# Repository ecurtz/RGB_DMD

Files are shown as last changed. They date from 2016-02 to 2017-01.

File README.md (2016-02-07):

# RGB_DMD LED Matrix Display for Pinball #

RGB_DMD is software for displaying either colorized signals from a pinball machine or color images from a host PC onto RGB LED matrix displays using the [Teensy 3.2](http://www.pjrc.com/teensy/index.html) development board and a custom carrier board. RGB_DMD was written by Eli Curtz, <eli@nuprometheus.com> but is built on top of open source work by many people, primarily the [SmartMatrix](http://docs.pixelmatix.com/SmartMatrix/library.html) display library.

## Contents ##
### License ###
The RGB_DMD source code is released under the MIT License.
### HEX Folder ###
Contains compiled .hex versions of the project, which can be loaded directly to the board using the Teensy Loader  or Teensy Qt applications.
### SRC Folder ###
Contains the Arduino / C++ source code for the project.
### UTIL Folder ###
Utilities for testing and configuring data.

## Building RGB_DMD ##

### Tools ###
[Arduino IDE](http://arduino.cc/en/main/software) is required for recompiling RGB_DMD from source or customizing the code.

[Teensyduino](http://www.pjrc.com/teensy/td_download.html) is a required plugin that adds Teensy support to the Arduino IDE as well as the Teensy Loader tool for transferring compiled code to the development board.

### Libraries
These are additional third party code required when building RGB_DMD. They are distributed as source on github and are installed as described under __Manual Installation__ at the [Arduino reference](https://www.arduino.cc/en/Guide/Libraries#toc5).

[SmartMatrix](https://github.com/ecurtz/SmartMatrix) is used for outputting the signal to the RGB matrix. Link is to my fork which is required for hardware compatibility and has some optimizations.

[FastCRC](https://github.com/FrankBoesing/FastCRC) is used to calculate a checksum for DMD frames so they can be uniquely identified.

### Settings ###
The Arduino IDE should be set to compile for Teensy by selecting __Teensy 3.1__ from the __Tools : Board__ menu in the Arduino IDE.

RGB_DMD should be built to run at the __96MHz optimized (overclock)__ setting using the __Tools : CPU Speed__ menu.

## Using DMD Input ##
Pinball machines use a set of 6 signals to control a plasma or LED DMD. RGB_DMD captures these inputs to determine which CPU system the pin is using and rebuild the display images.

__DOT CLOCK__: Repeatedly switches between high and low to mark when the dot data should be read.

__DOT DATA__: Will be either on or off for each of the 128 dots in a single row of the DMD.

__COLUMN LATCH__: Marks the end of the row of dot data.

__DISPLAY ENABLE__: Turns the actual display output on and off. By varying the display enable time the overall brightness can be adjusted, and varying the time for different data on the same row is used to produce the effect of multiple shades on a single color DMD.

__ROW CLOCK__: Moves to the next display row. Separate from the column latch because one row may be updated and latched several times with different data before the transition.

__ROW DATA__: Used with row clock to mark the transition from the last row back to the first.

## Using USB Input ##
RGB_DMD may be controlled over USB from a host computer to store settings for the DMD input or display full color images for homebrew pinball machines.
### Sending From Python ###
Using USB input from Python requires the [PySerial Extension](https://pyserial.readthedocs.org/en/latest/). If you are using [PyProcGame](http://pyprocgame.pindev.org) or the [Mission Pinball Framework](https://missionpinball.com) PySerial may already be installed.
### Sending From C/C++/C# ###

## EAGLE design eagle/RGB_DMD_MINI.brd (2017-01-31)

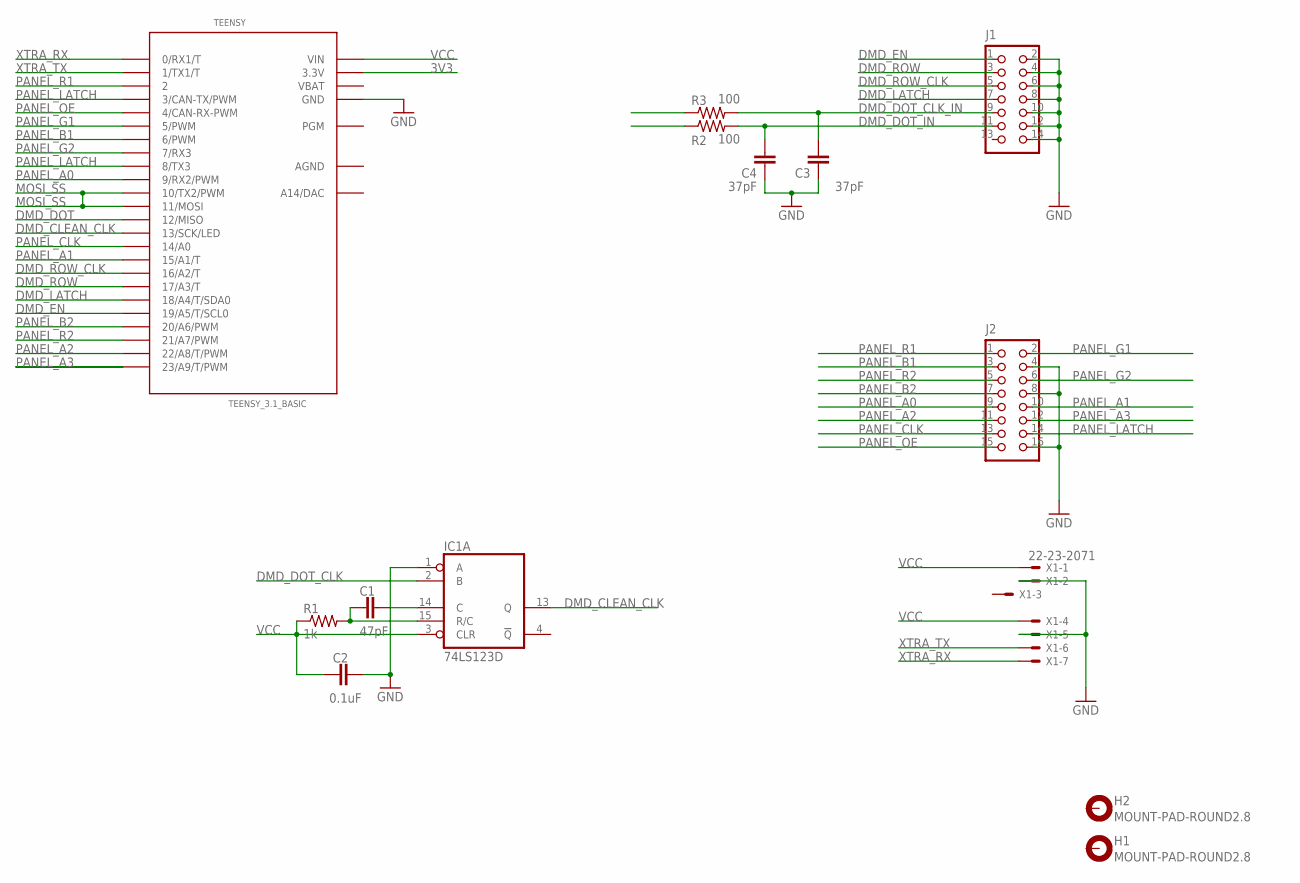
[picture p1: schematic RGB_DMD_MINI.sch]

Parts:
C1: 47pF; C0603
C2: 0.1uF; C0603
C3, C4: 37pF; C0603
H1, H2: MOUNT-PAD-ROUND2.8; 2,8-PAD
IC1: 74LS123D; SO16
J1: CON_HEADER_2X07-PTH-SHROUDED; PINSHRD_PTH_2X07
J2: CON_HEADER_2X08-PTH-SHROUDED; PINSHRD_PTH_2X08
R1: 1k; R0603
R2, R3: 100; R0603
TEENSY: TEENSY_3.1_BASIC
X1: 22-23-2071

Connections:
3V3: TEENSY.3.3V, TEENSY.3.3V1 (3.3V)
AGND: TEENSY.AGND
DMD_CLEAN_CLK: IC1.13 (Q), TEENSY.13 (13/SCK/LED)
DMD_DOT: R2.1, TEENSY.12 (12/MISO)
DMD_DOT_CLK: IC1.2 (B), R3.1
DMD_DOT_CLK_IN: C3.2, J1.9, R3.2
DMD_DOT_IN: C4.2, J1.11, R2.2
DMD_EN: J1.1, TEENSY.19/A5 (19/A5/T/SCL0)
DMD_LATCH: J1.7, TEENSY.18/A4 (18/A4/T/SDA0)
DMD_ROW: J1.3, TEENSY.17/A3 (17/A3/T)
DMD_ROW_CLK: J1.5, TEENSY.16/A2 (16/A2/T)
GND: C2.2, C3.1, C4.1, IC1.1 (A), IC1.8 (GND), J1.2, J1.4, J1.6, J1.8, J1.10, J1.12, J1.14, J2.4, J2.8, J2.16, TEENSY.GND, TEENSY.GND1 (GND), X1.2, X1.5
MOSI_SS: TEENSY.10 (10/TX2/PWM), TEENSY.11 (11/MOSI)
unnamed: C1.1, IC1.15 (R/C), R1.2
unnamed: C1.2, IC1.14 (C)
PANEL_A0: J2.9, TEENSY.9 (9/RX2/PWM)
PANEL_A1: J2.10, TEENSY.15/A1 (15/A1/T)
PANEL_A2: J2.11, TEENSY.22/A8 (22/A8/T/PWM)
PANEL_A3: J2.12, TEENSY.23/A9 (23/A9/T/PWM)
PANEL_B1: J2.3, TEENSY.6 (6/PWM)
PANEL_B2: J2.7, TEENSY.20/A6 (20/A6/PWM)
PANEL_CLK: J2.13, TEENSY.14/A0
PANEL_G1: J2.2, TEENSY.5 (5/PWM)
PANEL_G2: J2.6, TEENSY.7 (7/RX3)
PANEL_LATCH: J2.14, TEENSY.3 (3/CAN-TX/PWM), TEENSY.8 (8/TX3)
PANEL_OE: J2.15, TEENSY.4 (4/CAN-RX-PWM)
PANEL_R1: J2.1, TEENSY.2
PANEL_R2: J2.5, TEENSY.21/A7 (21/A7/PWM)
VBAT: TEENSY.VBAT
VCC: C2.1, IC1.3 (CLR), IC1.16 (VCC), R1.1, TEENSY.VIN, X1.1, X1.4
XTRA_RX: TEENSY.0 (0/RX1/T), X1.7
XTRA_TX: TEENSY.1 (1/TX1/T), X1.6

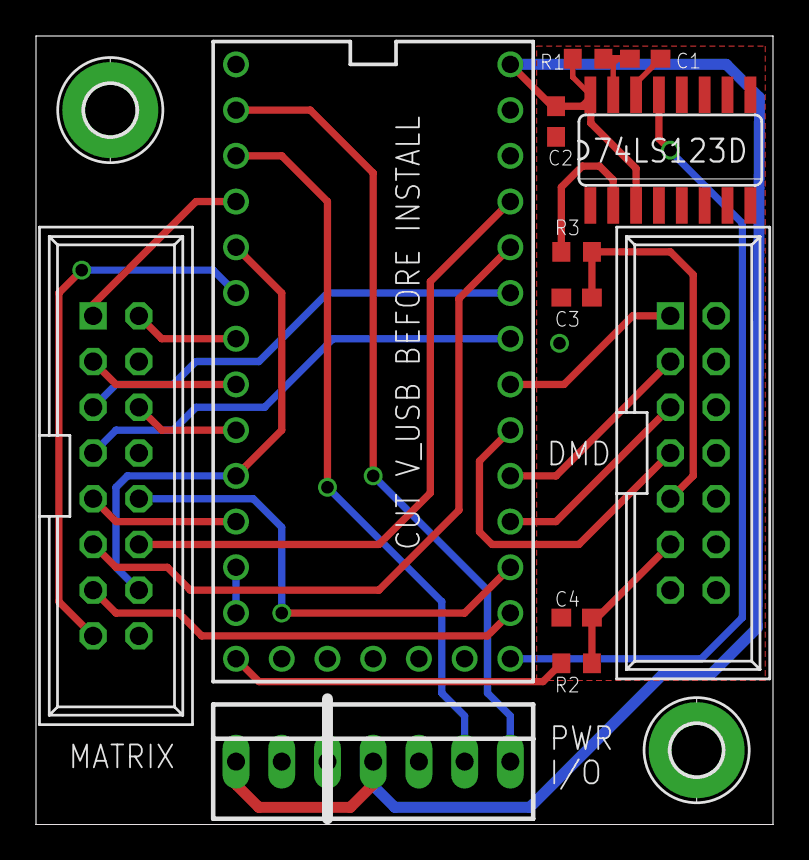
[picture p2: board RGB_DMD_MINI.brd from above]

Board: 2 copper layers, 40.9 x 43.8 mm, 14 parts (0 on the bottom side), 30 nets.

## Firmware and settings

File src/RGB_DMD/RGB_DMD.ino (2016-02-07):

// Copyright (c) 2015 Eli Curtz

#include <SmartMatrix3.h>
#include <MatrixHardware_RGB_DMD.h>

#include "BoardInfo.h"
#include "VersionInfo.h"
#include "Watchdog.h"
#include "Palettes.h"
#include "InputUSB.h"
#include "InputDMD.h"
#include "SplashScreen.h"
#include "PinballBrowser.h"
#include "MatrixSetup.h"

bool dmdInput = false;
bool usbInput = false;

// Palette data
// This is a default palette
// Defined here for convenience during testing
rgb24 testPalette[] = {
  {0x00, 0x00, 0x00}, // Used by 4 color DMD
  {0x1E, 0x1E, 0x1E}, // Nothing below 0x1E will survive color correction
  {0x26, 0x26, 0x26}, // so these two entries are cheated a little
  {0x33, 0x33, 0x33},
  {0x44, 0x44, 0x44},
  {0x55, 0x55, 0x55}, // Used by 4 color DMD
  {0x66, 0x66, 0x66},
  {0x77, 0x77, 0x77},
  {0x88, 0x88, 0x88},
  {0x99, 0x99, 0x99},
  {0xAA, 0xAA, 0xAA}, // Used by 4 color DMD
  {0xBB, 0xBB, 0xBB},
  {0xCC, 0xCC, 0xCC},
  {0xDD, 0xDD, 0xDD},
  {0xEE, 0xEE, 0xEE},
  {0xFF, 0xFF, 0xFF}  // Used by 4 color DMD
};

/*
 Initialize code sections, show splash, and wait for input from connected dmd or usb
*/
void setup()
{
  // Initialize hardware pins
  pinMode(MOSI, OUTPUT);
//  pinMode(GPIO_PIN_OE_TEENSY_PIN, OUTPUT);
//  digitalWriteFast(GPIO_PIN_OE_TEENSY_PIN, HIGH);
  // Initialize watchdog timer
  initializeWatchdog();
  // Initialize USB serial communication
  initializeInputUSB();
  // Initialize DMD communication
  initializeInputDMD();
  // Initialize software version information
  initializeVersionInfo();
  // Initialize hardware ID information
  initializeBoardInfo();
  // Initialize settings from EEPROM
  //initializeSettings();
  // Initialize Pinball Browser interface - must be AFTER initializeBoardInfo() for ID check
  initializePinballBrowser();
  
  // Configure matrix output
  matrix.addLayer(&backgroundLayer); 
  matrix.begin();
  matrix.setBrightness(64);
  matrix.setRefreshRate(120);
  backgroundLayer.enableColorCorrection(false);

  // Set a temporary test palette
  for (int i = 0; i < 16; i++) {
     colorCorrection(testPalette[i], globalPalette[i]);
  }
  setActivePalette(0);
  
  // Display splash screen
  delay(20);
  showSplashScreen(true);
  delay(1500);
  kickWatchdog();
  delay(1500);

  // Dump a little information
  printResetType();
  Serial.print("Hardware ID: "); Serial.println(idString);
  Serial.print("Software version: "); Serial.println(versionString);

  // Wait for USB or DMD data
  do {
    kickWatchdog();
    dmdInput = hasInputDMD();
    usbInput = hasInputUSB();
  } while (!dmdInput && !usbInput);

  // Clear the Screen
  backgroundLayer.fillScreen(globalPalette[0]);
  backgroundLayer.swapBuffers();
  backgroundLayer.fillScreen(globalPalette[0]);
  
  // Configure active input
  if (dmdInput) {
   configureInputDMD(); 
  }
  if (usbInput) {
    configureInputUSB();
  }

  Serial.println("Setup complete");
}

/*
 Repeat forever. Look for input, kick watchdog
*/
void loop()
{
  if ((dmdInput && handleInputDMD()) || (usbInput && handleInputUSB())) {
    kickWatchdog();
  }
}

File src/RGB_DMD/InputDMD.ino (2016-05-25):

// Copyright (c) 2015 Eli Curtz

#include <DMAChannel.h>
#include <FastCRC.h>

#include "InputDMD.h"
#include "MatrixSetup.h"
#include "Palettes.h"

// Modified input method using DMA completion
//#define DMA_COMPLETION_ISR 1

// Comparison constants
#define SMALLER -1
#define EQUAL 0
#define LARGER 1

// Dot data
#define PLANE_COUNT 4
#define PLANE_COUNT_WHITESTAR 2
#define PLANE_BLEND_WPC 3
#define PLANE_SIZE ROW_COUNT * ROW_LENGTH
#define PLANE_BYTES PLANE_SIZE * sizeof(uint16_t)
uint16_t plane_buffer[ROW_LENGTH * 2];
uint16_t planes[PLANE_SIZE * PLANE_COUNT];
typedef uint16_t wpc_plane[ROW_COUNT][ROW_LENGTH];
wpc_plane* wpc_planes = (wpc_plane*) planes;
typedef uint16_t whitestar_plane[PLANE_COUNT_WHITESTAR][ROW_LENGTH];
whitestar_plane* whitestar_planes = (whitestar_plane*) planes;
typedef uint16_t sam_plane[PLANE_COUNT][ROW_LENGTH];
sam_plane* sam_planes = (sam_plane*) planes;

// Checksums
FastCRC32 CRC32;
uint32_t checksums[ROW_COUNT];
uint8_t checksumRowFirst = 12;
uint8_t checksumRowLast = 18;
uint8_t checksumByteFirst = 0;
uint8_t checksumByteLast = 5;
uint32_t lastCheck;

// Variables used in interrupts
volatile uint32_t plane = 0;
volatile uint32_t row = 0;
volatile bool rowZero = false;
volatile bool gotRow = false;
volatile uint32_t receivedRows = 0;

// DMD signal
uint8_t dmdDataFormat = FORMAT_UNKNOWN;
uint8_t planesPerRow = 1;
uint8_t planeOrder[4] = {0, 1, 2, 3};
unsigned long planeStart;
unsigned long planeTimes[PLANE_COUNT];
unsigned long activePlaneTimes[PLANE_COUNT];
bool timingChanged = false;

// Input pins
const static uint8_t  DMD_ROW_DATA = 17;
#define DMD_ROW_DATA_BITMASK CORE_PIN17_BITMASK
const static uint8_t  DMD_ROW_CLK = 16;
#define DMD_ROW_CLK_BITMASK CORE_PIN16_BITMASK
const static uint8_t  DMD_DOT_LATCH = 18;
#define DMD_DOT_LATCH_BITMASK CORE_PIN18_BITMASK
const static uint8_t  DMD_OE = 19;
#define DMD_OE_BITMASK CORE_PIN19_BITMASK

const static uint8_t  DMD_CS = MOSI;

// DMA channel
DMAChannel* dmaSPI0rx;

/*
 Compare two elapsed times with some slop to allow minor variation
*/
int8_t compareIntervals(uint32_t interval1, uint32_t interval2)
{
  uint32_t intervalFraction;
  if (interval1 > 32)
    intervalFraction = interval1 >> 3;
  else
    intervalFraction = interval1 >> 2;
  
  if ((interval1 + intervalFraction) < interval2)
    return LARGER;
  if ((interval1 - intervalFraction) > interval2)
    return SMALLER;
  return EQUAL;
}

/*
 Set the pin modes used by the DMD input signals
*/
void initializeInputDMD()
{
  pinMode(DMD_ROW_DATA, INPUT);
  pinMode(DMD_ROW_CLK, INPUT);
  pinMode(DMD_DOT_LATCH, INPUT/*_PULLDOWN*/);
  *portConfigRegister(DMD_DOT_LATCH) |= PORT_PCR_PE;
  *portConfigRegister(DMD_DOT_LATCH) &= ~PORT_PCR_PS;
  pinMode(DMD_OE, INPUT/*_PULLDOWN*/);
  *portConfigRegister(DMD_OE) |= PORT_PCR_PE;
  *portConfigRegister(DMD_OE) &= ~PORT_PCR_PS;
  pinMode(DMD_CS, OUTPUT);
}

/*
 Look for a DMD signal on the input pins
*/
bool hasInputDMD()
{
  // Enable counter interrupts to check for DMD signal
  row = 0; plane = 0;
  attachInterrupt(digitalPinToInterrupt(DMD_ROW_CLK), row_count_isr, FALLING);
  attachInterrupt(digitalPinToInterrupt(DMD_DOT_LATCH), plane_count_isr, FALLING);
  // Wait 1/8th of a second
  delay(128);
  // Disable counter interrupts
  detachInterrupt(digitalPinToInterrupt(DMD_ROW_CLK));
  detachInterrupt(digitalPinToInterrupt(DMD_DOT_LATCH));
  
  if (row < ROW_COUNT)
    return false;

  planesPerRow = (plane + (ROW_COUNT >> 3)) / row;
  Serial.print(plane); Serial.print(" : "); Serial.println(row);
  Serial.print("Planes per row: "); Serial.println(planesPerRow);
  
  if ((planesPerRow == 0) || (planesPerRow > PLANE_COUNT))
    return false;

  // Enable timer interrupts to calculate plane order
  row = 0; plane = PLANE_COUNT;
  attachInterrupt(digitalPinToInterrupt(DMD_ROW_CLK), row_clk_isr_timing, FALLING);
  attachInterrupt(digitalPinToInterrupt(DMD_DOT_LATCH), dot_latch_isr_timing, FALLING);
  attachInterrupt(digitalPinToInterrupt(DMD_OE), oe_isr_timing, FALLING);
  // Wait 1/16th of a second
  delay(64);
  // Disable timer interrupts
  detachInterrupt(digitalPinToInterrupt(DMD_ROW_CLK));
  detachInterrupt(digitalPinToInterrupt(DMD_DOT_LATCH));
  detachInterrupt(digitalPinToInterrupt(DMD_OE));
  
  calculatePlaneTimings();
  Serial.print("Format: "); Serial.println(dmdDataFormat);
 
  row = 0; plane = 0;
  return true;
}

/*
 Configure DMD input
*/
void configureInputDMD()
{  
  // Configure pins for use by SPI0
  CORE_PIN10_CONFIG = PORT_PCR_MUX(2) | PORT_PCR_PE | PORT_PCR_PS;
  /*
   Don't enable MOSI for SPI0 because we use it to replace CS on
   platforms where the shift register timings aren't valid for SPI
  */
  // CORE_PIN11_CONFIG = PORT_PCR_DSE | PORT_PCR_MUX(2);
  CORE_PIN12_CONFIG = PORT_PCR_MUX(2) | PORT_PCR_PE;
  CORE_PIN13_CONFIG = PORT_PCR_MUX(2);
  digitalWriteFast(DMD_CS, HIGH);
  
  // Enable clock to SPI0
  SIM_SCGC6 |= SIM_SCGC6_SPI0;
  SPI0_MCR = SPI_MCR_HALT | SPI_MCR_MDIS | SPI_MCR_PCSIS(1<<0);
  
  // 16 bit transfers, on rising edge
  SPI0_CTAR0_SLAVE = SPI_CTAR_FMSZ(15);
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

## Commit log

2016-02-09 Crazy SAM bug where it missed the marker to begin SPI because of the timing between the IRQ and the row clock. Disabled the IRQ until frame processing begins.
    [DMD_OUTPUT_SAM.ino, InputDMD.ino]
2016-02-18 Update to the test signal generators - Gottlieb/Premier added, and a bug in WPC fixed
    [DMD_OUTPUT_PREMIER.ino]
2016-02-29 Initial code for alternate input relying on SPI transfer completion rather than end of row signals. Fixed (?) stray pixel getting set in field which appeared in certain combinations of build settings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
    [InputDMD.ino]
2016-06-12 Added weird extra row zero latch from early Whitestar games and reversed biplane order.
    [DMD_OUTPUT_WHITESTAR.ino]
2017-01-31 Added Eagle files for the RGB DMD Mini Teensy 3.2 carrier board.
    [RGB_DMD_MINI.brd, RGB_DMD_MINI.sch]
2017-06-15 Updated simulator code. Changed pins to support board I have extras of and added weird 33rd row to Gottlieb/Premier simulator.
2020-08-31 Added an svg file of a basic DMD sized frame for attaching the panels. In the format used by Ponoko.com for laser cutting, so lines are very faint by default.
